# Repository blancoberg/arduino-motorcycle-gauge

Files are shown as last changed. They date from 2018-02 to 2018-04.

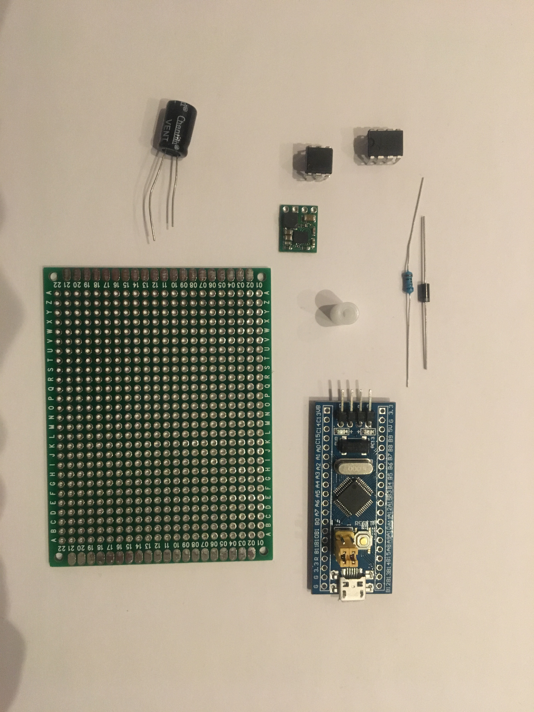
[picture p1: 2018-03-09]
bitmaps/krets.jpg

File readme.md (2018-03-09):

# Gauges for motorcycle

### Functions

* Speedometer
* tripmeter
* Tachometer
* Fuelmeter
* 0-60 timer :)

### Software needed
* Arduino IDE
* Stm32duino

### Parts needed

* 1 US1881 hall sensor
* 2 x 4n35 optocouplers
* 1 555-timer
* 50 ohm resistor
* 6 x 1000 ohm resistor
* 2 x 10k ohm resistor
* stm32f1c8 board
* 1 2n222 diode or similar
* 128x64 display
* 30x30cm acrylic plastic
* some cables for wiring

### Schematics

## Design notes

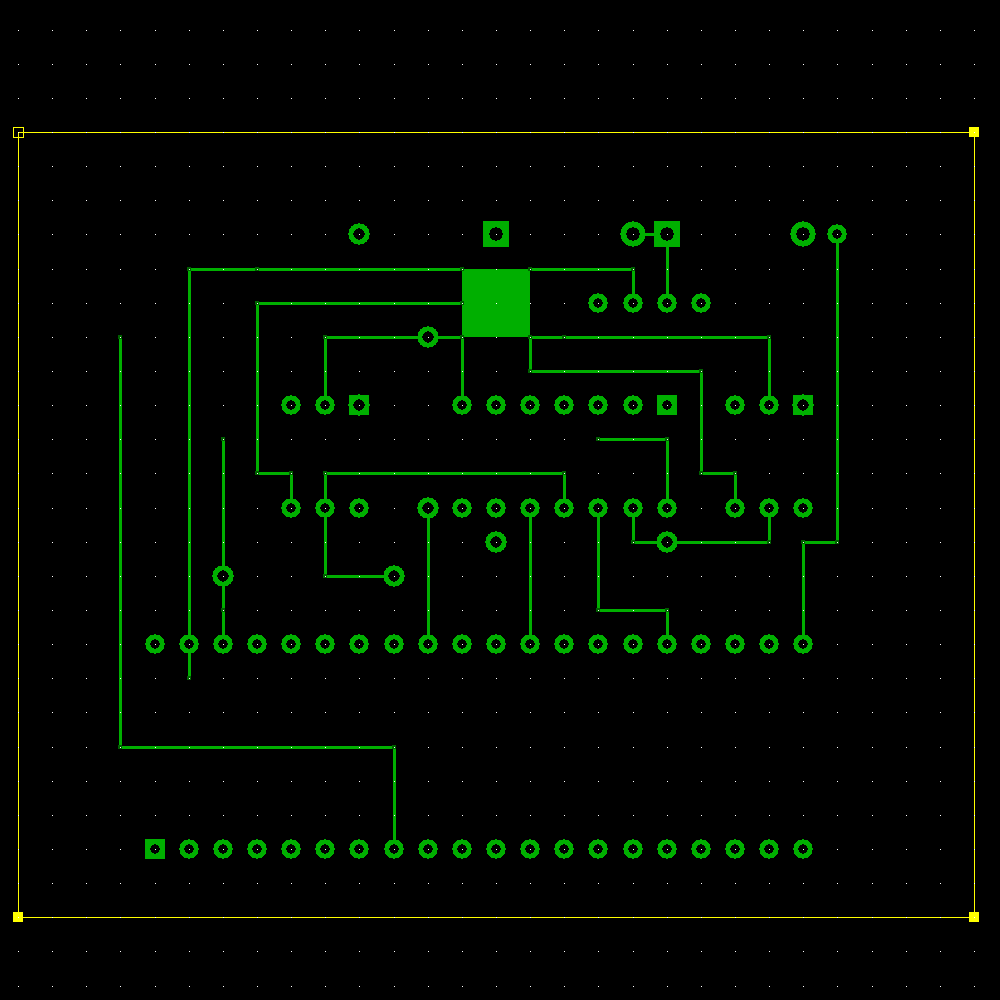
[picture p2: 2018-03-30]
bitmaps/_0003_Layer-3.png

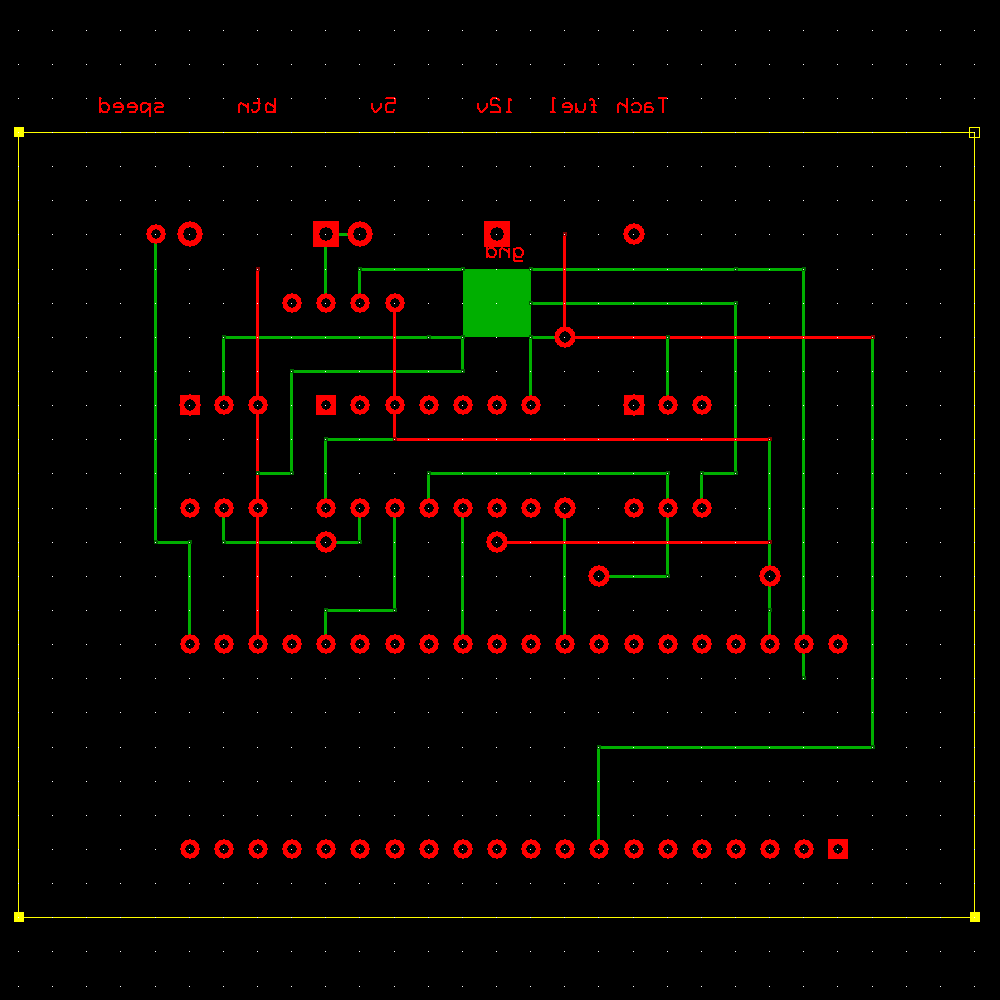
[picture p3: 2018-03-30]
bitmaps/_0001_Layer-2-copy.png

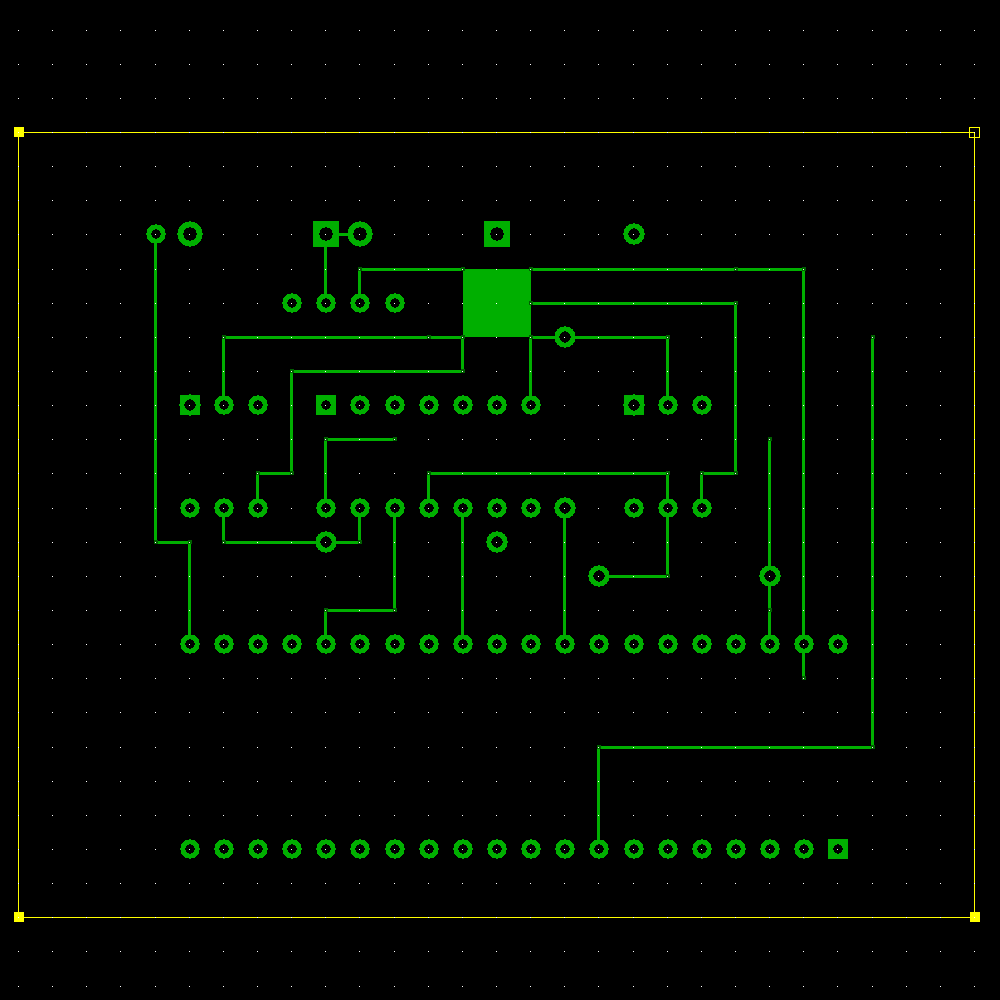
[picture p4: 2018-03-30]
bitmaps/_0000_Layer-3-copy.png

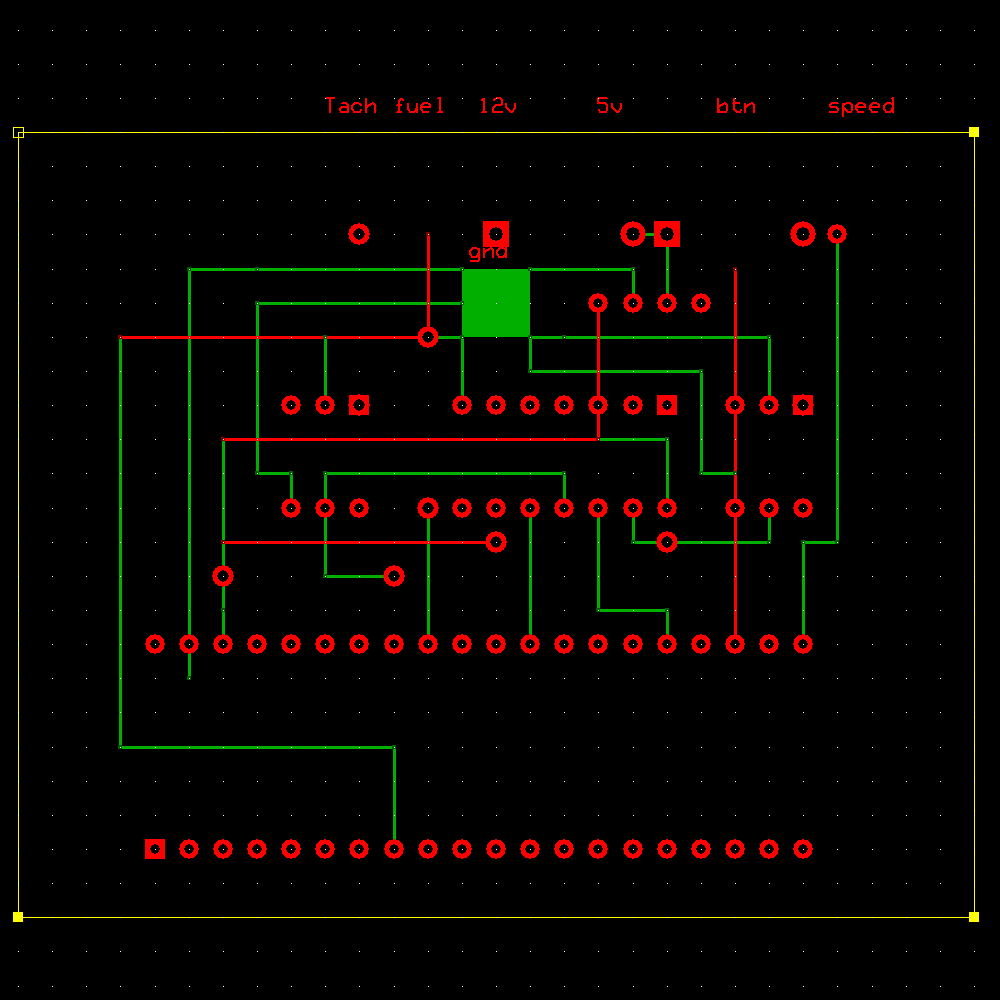
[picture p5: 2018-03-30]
bitmaps/_0004_Layer-2.png

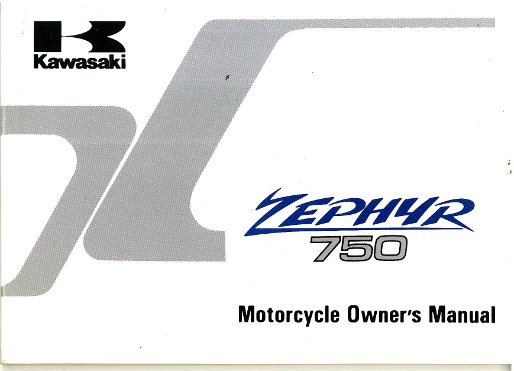
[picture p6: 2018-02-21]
bitmaps/zephyr.jpg

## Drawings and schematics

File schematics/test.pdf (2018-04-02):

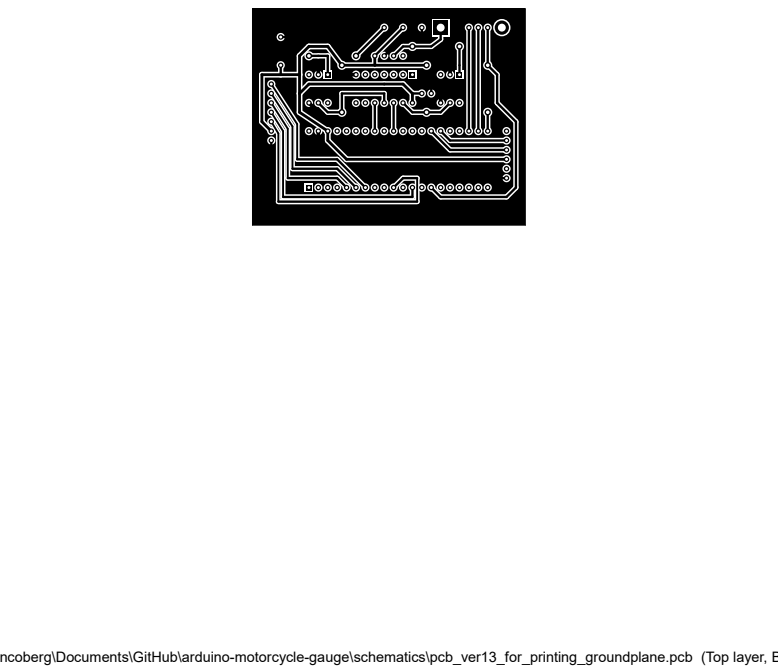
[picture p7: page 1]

C:\Users\blancoberg\Documents\GitHub\arduino-motorcycle-gauge\schematics\pcb_ver13_for_printing_groundplane.pcb (Top layer, Bottom layer)

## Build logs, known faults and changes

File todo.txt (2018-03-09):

koppla till knapp till arduino.   x
bensinmätare
create tachometer   x
create odometer   x
  distance    x
    total   x
    current x
  speed x
  0-100 built in game x
    show 0-100 time
      if time since total stop is less than 15 seconds

förbered kablage för plug&play

lägg till röd led
  blinkar när tachometer.rpm > 9000

Ta bort test animation i tachometer.      x
Testa hall sensor     x
Lägg till ny hall sensor med pullup resistor
lägg till kondensator och testa tach sensor hemma, debounca
åk till Huddinge och testa fuel sensor och tach sensor
löd ihop allt i ett kretskort
bygg låda
Lägg till ny grafik för rpm     x
Ändra scener till klasser istället    x
lägg till scener
  main
    main graphic draw function()
      drawSpeed();            x
      drawRpm();              x
      drawFuelLevel(x,y);     x
    drawMini(header,value);   x

  distance tot                 x
    action()                    x
      no action               x
  tripmeter                     x
    action()                  x
      reset tripmeter         x
  rpm value
    action()

  acceleration                x
    action()
      goto special screen

  save current scene          x

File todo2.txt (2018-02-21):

Få skärmen att fungera		x
använd u8g2 biblioteket istället	x
switcha ut reedswitchen till en hall sensor		x
rpm grafik
bensingrafik
tripmätargrafik

Lägg till knapp				x
skapa NavigationManager		x
 och scenes
	navigera i scenmanager med kort knapptryck		x
	långt knapptryck interagerar med aktuell scen		x
scener
	standard
	tripmätare
	varvräknare

Lägg till voltmätare för batteriet

Grafik:
	Main ( hastighet, bensin, tripmätare och varvräknare, batteri )
  Total tripmätare.
	RPM - tydlig siffra. Bra för kalibrering
	settings
    wheel dimensions
    magnets
    engine
      ignition coils
      cylinders
          if coils< cylinders = wasted spark ( spark every revolution) || spark every other

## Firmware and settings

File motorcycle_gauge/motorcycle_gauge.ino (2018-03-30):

#include <EEPROM.h>
#include <U8g2lib.h>


#ifdef U8X8_HAVE_HW_SPI
#include <SPI.h>
#endif

/*
#ifdef U8X8_HAVE_HW_I2C
#include <Wire.h>
#endif
*/


//U8G2_SSD1306_128X64_NONAME_F_4W_SW_SPI u8g2(U8G2_R0, /* clock=*/ PA0, /* data=*/ PA1, /* cs=*/ PA4, /* dc=*/ PA3, /* reset=*/ PA2); // stm32 software spi
//U8G2_SSD1306_128X64_NONAME_F_4W_SW_SPI u8g2(U8G2_R0, /* clock=*/ 3, /* data=*/ 4, /* cs=*/ 7, /* dc=*/ 6, /* reset=*/ 5); // Arduino UNO
//U8G2_SSD1306_128X64_NONAME_F_4W_HW_SPI u8g2(U8G2_R0, /* cs=*/ 10, /* dc=*/ 8, /* reset=*/ 9); // arduino uno hardware
U8G2_SSD1306_128X64_NONAME_F_4W_HW_SPI u8g2(U8G2_R0, /* cs=*/ PA2, /* dc=*/ PA1, /* reset=*/ PA0); // STM32 hardware SPI


namespace Batterymeter{
  float value = 0;
  int batteryPin = 0;

  void update(){
    Batterymeter::value = (analogRead(batteryPin)/4095.0) * 3.3;
  }
  
  void init(int pin){
    pinMode(pin,INPUT);
    batteryPin = pin;
  }
}

namespace Fuelmeter{

  int fuelPin = 0;
  int controlPin = 0;
  int value = 0;
  int resFull = 10;
  int resEmpty = 100;
  void update(){

    digitalWrite(controlPin,HIGH);

    double v = analogRead(fuelPin);
    double voltageIn = 3.3;
    //value = analogRead(fuelPin);
    // vOut = R2/(R1+R2) * vIn
    double voltageOut = (v/4095.0) * 3.3;
    
    if(voltageOut==0)
      voltageOut= 0.001;
    //double R1 = (3.3*50)/voltageOut - 50;
    /*
     vOut/vIn = r2/(50+r2)
     (vOut/vIn)*(50+r2) = r2
     50(vOut/vIn)= 1r2 - (vOut/vIn)r2
     50(vOut/vIn)/(1-vOut/vIn) = r2
     */
    double R1 = 47+20; // R1 value + 20 ohm input resistance
    //double R2 = (47 * (voltageOut/voltageIn))/(1-(voltageOut/voltageIn));
    double R2 = (voltageOut*R1)/(voltageIn-voltageOut);
    
    double proc = min(1,max(0,1.0-((R2-resFull)/(resEmpty-resFull))));
    /*
    Serial.print("R1");
    Serial.println(R1);
    Serial.print("R2");
    Serial.println(R2);

    Serial.print("proc");
    Serial.println(proc*100);
    */
    value = proc*100;
    digitalWrite(controlPin,LOW);
  }
  
  void init(int pin,int pinControl){
    pinMode(pinControl,OUTPUT);
    fuelPin = pin;
    controlPin = pinControl;
  }
  
}


/*
 * TACHOMETER
 */

namespace Tachometer {

  unsigned long lastTime = micros();
  double maxRPM = 11000;
  double redLine = 10000;
  int rpm = 0;
  double rpmSmooth = 0.0;
  double cosCounter = 0.0;
  boolean state = false;
  int coilPin = 0;
  bool locked = false;
  int counter = 0;
  
  void onCoilEvent(){

      
            
          
          
       
            
        
        rpm = 1.0/ (   (micros()-lastTime)/1000000.0  ) * 60.0;
        lastTime = micros();
              
            
        
          
        
        
                                                 
            
          
      //rpm = random(0,maxRPM);
  }

  void update(){

    
    // reset rpm 
    if(micros()-lastTime > 500000){
      rpm = 0;
    }
    

    
    
    
  }
  
  void init(int pin){

    coilPin = pin;
    //pinMode(pin,DIGITAL);
    //pinMode(pin,INPUT);
    attachInterrupt(digitalPinToInterrupt(coilPin), onCoilEvent, RISING);
  }

  
}

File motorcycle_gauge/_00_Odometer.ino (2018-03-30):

/*
 *

 *
  ODOMETER

  load distance variable from memory    x
  load tripmeter from memory  x
  save variables after every x revolutions  x

  reset speed if nothing has changed for 2 seconds.

  save variables to EEPROM when > 5 min has passed and speed it lower than 10 km / h.   x
  that will give it enough time when stopping the bike to save any changed data.    x

  if onManget when speed==0, start speedCounter   x
    when speed >= 100 save time and run event     x


 */

namespace Odometer {

  double distance = 0.0; //0.0f;//EEPROM.readDouble(2);
  double tripMeter = 0.0;//EEPROM.readDouble(3);
  
  double accelerationTime = 0;
  
  int amountOfMagnets = 1;                          // amount of magnets used on the wheel
  int wheelDiameter = 70;                           // wheel diameter in mm
  double wheelCircumference = wheelDiameter * PI;
  int pinId = 0;
  double speed = 0;
  double lastTime = 0;
  double lastSaved = 0;
  boolean speedCounterStarted = false;
  double speedCounter = 0;
  boolean state = false;

  void EEPROM_writeDouble(int ee, double value)
  {
     byte* p = (byte*)(void*)&value;
     for (int i = 0; i < sizeof(value); i++)
         EEPROM.write(ee++, *p++);
  }
  
  double EEPROM_readDouble(int ee)
  {
     double value = 0.0;
     byte* p = (byte*)(void*)&value;
     for (int i = 0; i < sizeof(value); i++)
         *p++ = EEPROM.read(ee++);
     return value;
  }
  
  void draw(){
    //Serial.println(F("odometer.draw"));
  }

  void loadState(){

    
    distance = EEPROM_readDouble(0);
    tripMeter = EEPROM_readDouble(8);


    Serial.print(" distance =");
    Serial.println(String(round(distance)));

    Serial.print(" tripMeter =");
    Serial.println(String(round(tripMeter)));
    
    distance = isnan(distance) == true ? 0 : distance;
    tripMeter =  isnan(tripMeter) == true? 0 : tripMeter;
    
  }
  
  void saveState(){

      if(millis()-lastSaved > 1000){ // handle bouncing when power is switched off
        
        
        //u8g2.setPowerSave(1);
        EEPROM_writeDouble(0,distance);
        EEPROM_writeDouble(8,tripMeter);
        lastSaved = millis();
      }
      
//    //EEPROM.writeDouble(2,Odometer::distance);
   // EEPROM.writeDouble(3,Odometer::tripMeter);
  }

  void resetSpeed(){
    if(speed != 0){
      speed = 0;
      Serial.println(F("reset speed"));
    }

  }

  void resetTrip(){
    Odometer::tripMeter = 0;
    //save();
  }

  void onMagnet(){

    

      // start 0-100km/h counter //
      if(speed == 0 && speedCounterStarted==false){
          speedCounter = micros();
          speedCounterStarted=true;
      }

      if(speedCounterStarted == true){
        accelerationTime = micros()-speedCounter;
      }

      if(speed >= 100 && speedCounterStarted == true){
        speedCounterStarted = false;
        accelerationTime = (micros()-speedCounter);
        //Serial.print(F("0-100 time:"));
        //Serial.println((micros()-speedCounter)/1000000);
      }

      double dist = (Odometer::wheelCircumference/100)/amountOfMagnets;
      Odometer::distance+=dist;
      Odometer::tripMeter+=dist;

      double timePassed = micros()-Odometer::lastTime;
      Odometer::speed = ((dist)/(timePassed/1000000) * 3600)/1000;
      //Serial.println(Odometer::speed);
      Odometer::lastTime = micros();
      state = true;

     


  }

  void init(int pin){


    


    pinId = pin;
    //Serial.print(F("odometer.init"));
    //Serial.println(Odometer::distance);
    
   // pinMode(pinId,INPUT);
    attachInterrupt(digitalPinToInterrupt(pinId), onMagnet, FALLING);


  }

}

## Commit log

2018-02-21 converted to stm32
    [wiring.fzz]
2018-02-22 Fuel sensor / fuelmeter
    Fuel sensor is now working
2018-02-25 data save
    Data saves when device is shut down
    [wiring2.fzz]
2018-03-09 structure
    Put all scenes in seperate classes.
    Fixed a bug when writing with EEPROM causing the sketch to hang.
    [_00_Odometer.ino, _01_Scene_Trip.ino, _06_SceneManager.ino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]
2018-03-19 pcb schematics
2018-03-30 new pcb design
2018-04-02 new pcb designs
    * Added ground plane. Probably the final design
